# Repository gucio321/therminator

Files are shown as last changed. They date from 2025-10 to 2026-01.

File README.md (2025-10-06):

# Intro

This is a repository containing resources for my enviroumental physics project.

# Goals

The main goal of this project is to compare various types of thermal sensors in terms of their accuracy.

The expected result of the experiment is a decent set of data obtained automatically with a microcontroller setup.

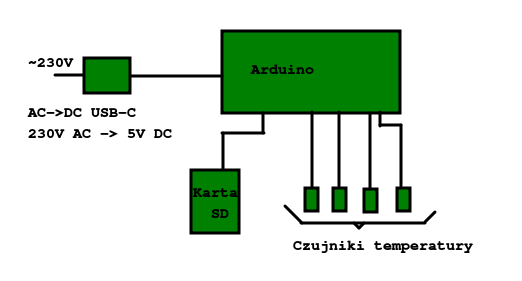
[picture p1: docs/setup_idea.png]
Setup overview


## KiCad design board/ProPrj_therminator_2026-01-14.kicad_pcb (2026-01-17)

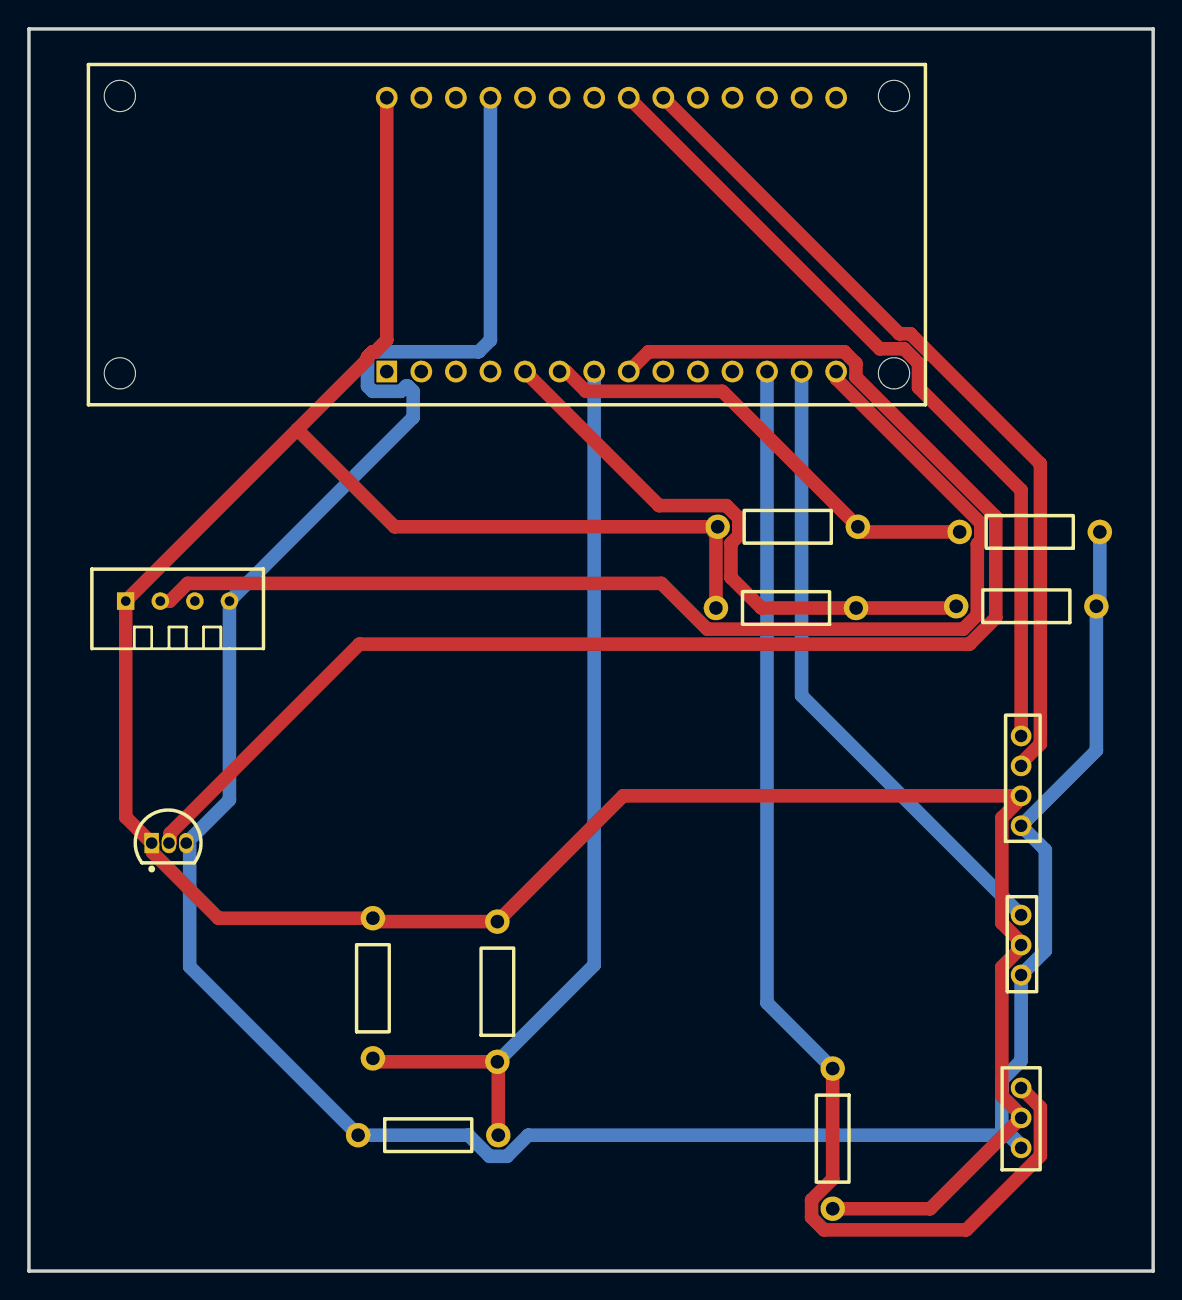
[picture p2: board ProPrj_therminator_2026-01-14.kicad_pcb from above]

Board: 2 copper layers, 82.6 x 91.3 mm, 14 parts (0 on the bottom side), 11 nets.

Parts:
DHT11: SENSOR-TH_DHT11-1
DHT22: DHT22-cable
DS18B20-1: DS18B20-cable
LCD-1: LCD-cable
LM35: TO-92-3_L4.8-W3.7-P1.27-L
NTC: RES-TH_BD2.3-L6.3-P10.30-D0.6
PT100-1, PT100-2: RES-TH_BD2.3-L6.3-P10.30-D0.6
R4: RES-TH_BD2.3-L6.3-P10.30-D0.6
RPom1, RPom2, RPom3, RPom4: RES-TH_BD2.3-L6.3-P10.30-D0.6
U1: COMM-TH_28P-L61.5-W25.0-P2.54

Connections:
$1N461: DHT11.1, DHT22.2, DS18B20-1.2, LCD-1.2, LM35.1, R4.2, RPom1.2, RPom2.2, RPom3.2, RPom4.2, U1.28
$1N571: DHT11.2, U1.14
$1N609: LM35.2, U1.8
$1N615: DHT11.4, DHT22.1, DS18B20-1.1, LCD-1.1, LM35.3, NTC.1, PT100-1.1, PT100-2.1, U1.25
$1N842: NTC.2, RPom1.1, RPom2.1, U1.7
$1N1258: DHT22.3, U1.13
$1N1408: DS18B20-1.3, R4.1, U1.12
$1N1586: PT100-1.2, RPom3.1, U1.6
$1N1590: PT100-2.2, RPom4.1, U1.5
$1N1838: LCD-1.3, U1.20
$1N1847: LCD-1.4, U1.21

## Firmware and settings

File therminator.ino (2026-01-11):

#include <DHT.h>
#include <OneWire.h>
#include <DallasTemperature.h>
#include <LiquidCrystal_I2C.h>
#include <SD.h>
#include <SPI.h>

const auto FILENAME = "datafile.csv";
const auto DHT11_PIN = 5;
const auto DHT22_PIN = 4;
const auto LM35_PIN = A6;
const auto DS18B20_PIN = 3;
const auto NTC_PIN = A5;
const auto NTC_R = 180000/2;
const auto VREF = 1.0;
auto const SUPPLY_V = 5.04;
auto const PT100_PIN = A4;
double const PT100_R = 673;
double const PT100_WIRES_R = 1.2;

DHT dht11(DHT11_PIN, DHT11);
DHT dht22(DHT22_PIN, DHT22);
OneWire oneWire(DS18B20_PIN);
DallasTemperature ds18b20(&oneWire);
LiquidCrystal_I2C lcd(0x27,  16, 2);

const int N_SENSORS = 7;
double record[N_SENSORS] = {0};
unsigned long MEASURE_IDX = 0;
char** names = new char*[N_SENSORS] {
  (char*)"DHT11 [oC]",
  (char*)"DHT22 [oC]",
  (char*)"LM35 [oC]",
  (char*)"DS18B20 [oC]",
  (char*)"NTC [R]",
  (char*)"PT100 [R]",
  (char*)"PT100 [oC]"
};

enum SensorType {
  DHT11_SENSOR,
  DHT22_SENSOR,
  LM35_SENSOR,
  DS18B20_SENSOR,
  NTC_SENSOR_R,
  PT100_SENSOR_R,
  PT100_SENSOR
};

int currentPage = 0;

void setup() {
  Serial.begin(9600);
  dht11.begin();
  dht22.begin();
  ds18b20.begin();
  analogReference(AR_INTERNAL1V0);

  lcd.init();
  lcd.backlight();
  lcd.setCursor(0,0);
  lcd.print("Hello from the");
  lcd.setCursor(0,1);
  lcd.print("Therminator!");
  
  // init SD card
  if (!SD.begin(SDCARD_SS_PIN)) {
    Serial.println("Cannott initialize SD card!");
    lcd.clear();
    lcd.setCursor(0,0);
    lcd.print("SD init failed!");
    bool backlight = true;
    while (1) {
      if (backlight) {
        lcd.backlight();
        backlight = false;
      } else {
        lcd.noBacklight();
        backlight = true;
      }
      delay(1000);
    }
  }

  Serial.println("SD init OK");
  lcd.clear();
  lcd.print("SD init OK.");
  lcd.setCursor(0,1);
  lcd.print("Saving header...");
  // save header
  String headerString = "#Idx,time,";
  for (int i = 0; i < N_SENSORS; i++) {
    headerString += String(names[i]);
    if (i < N_SENSORS - 1) {
      headerString += ",";
    }
  }
  File dataFile = SD.open(FILENAME, FILE_WRITE);
  if (dataFile) {
    dataFile.println(headerString);
    dataFile.close();
    Serial.println("Header saved: " + headerString);
  } else {
    Serial.println("Error opening file to save header!");
    lcd.clear();
    lcd.setCursor(0,0);
    lcd.print("SD write error!");
    bool backlight = true;
    while (1) {
      if (backlight) {
        lcd.backlight();
        backlight = false;
      } else {
        lcd.noBacklight();
        backlight = true;
      }
      delay(500);
    }
  }

}

void loop() {
  Serial.println("===========BEGIN============");
  MEASURE_IDX++;
  dht11Read();
  dht22Read();
  lm35Read();
  ds18b20Read();
  ntcRead();
  pt100Read();
  Serial.println("============END=============");
  // print the record on the screen

  currentPage++;
  if (currentPage >= N_SENSORS) {
    currentPage = 0;
  }

  // prepar data for save
  String dataString = String(MEASURE_IDX) + "," + String(millis()) + ",";
  for (int i = 0; i < N_SENSORS; i++) {
    dataString += String(record[i]);
    if (i < N_SENSORS - 1) {
      dataString += ",";
    }
  }

  lcd.print("SAVE!!");
  File dataFile = SD.open(FILENAME, FILE_WRITE);
  if (dataFile) {
    dataFile.println(dataString);
    dataFile.close();
    Serial.println("Data saved: " + dataString);
  } else {
    Serial.println("Error opening file!");
    lcd.clear();
    lcd.setCursor(0,0);
    lcd.print("SD write error!");
    bool backlight = true;
    while (1) {
      if (backlight) {
        lcd.backlight();
        backlight = false;
      } else {
        lcd.noBacklight();
        backlight = true;
      }
      delay(500);
    }
  }
  lcd.print("OK");

  lcd.clear();
  lcd.setCursor(0,0);
  lcd.print(names[currentPage]);
  lcd.setCursor(0,1);
  lcd.print("T=");
  lcd.print(record[currentPage]);
  lcd.print("  ");
  lcd.print(MEASURE_IDX);

  delay(1000);
}

void dht11Read() {
  Serial.print("DHT11: T = ");
  double temp = dht11.readTemperature();
  record[DHT11_SENSOR] = temp;
  Serial.print(temp);
  Serial.print(" *C\n");
}

void dht22Read() {
  Serial.print("DHT22: T = ");
  record[DHT22_SENSOR] = dht22.readTemperature();
  Serial.print(record[1]);
  Serial.print(" *C\n");
}

void lm35Read() {
  Serial.print("LM35: T = ");
  auto rawVal = analogRead(LM35_PIN);
  auto voltage = (VREF / 1023.0) * rawVal; // Convert ADC value to voltage
  auto temp = voltage * 100.0; // LM35 outputs 10mV per degree Celsius
  record[LM35_SENSOR] = temp;
  Serial.print(temp);
  Serial.print(" *C\n");
}

void ds18b20Read() {
  ds18b20.requestTemperatures();
  delay(1500);
  Serial.print("DS18B20: T = ");
  record[DS18B20_SENSOR]= ds18b20.getTempCByIndex(0);
  Serial.print(record[DS18B20_SENSOR]);
  Serial.print(" *C\n");
  Serial.println(ds18b20.getDeviceCount());
}

void ntcRead() {
  double rawVal = analogRead(NTC_PIN);
  Serial.print("NTC: ADC = ");
  Serial.print(rawVal);
  Serial.print("\n");

  double ntcV = rawVal / 1023.0 * VREF;
  Serial.print("NTC: V = ");
  Serial.print(ntcV);
  Serial.print(" V\n");

  double ntcR = ntcV*NTC_R/((SUPPLY_V - ntcV));
  Serial.print("NTC: R = ");
  Serial.print(ntcR);
  Serial.print(" Ohm\n");
  record[NTC_SENSOR_R] = ntcR;

  double B = 3380000;
  double ntcT = B/(log(ntcR/NTC_R) + B/298.15) - 273.15;
  Serial.print("NTC: T = ");
  Serial.print(ntcT);
  Serial.print(" *C\n");
}

void pt100Read() {
  double rawVal = analogRead(PT100_PIN);
  Serial.print("PT100: ADC = ");
  Serial.print(rawVal);
  Serial.print("\n");

  double pt100V = rawVal / 1023.0 * VREF;
  Serial.print("PT100: V = ");
  Serial.print(pt100V);
  Serial.print(" V\n");

  double pt100R = pt100V*PT100_R/((SUPPLY_V - pt100V)) - PT100_WIRES_R;
  Serial.print("PT100: R = ");
  Serial.print(pt100R);
  Serial.print(" Ohm\n");
  record[PT100_SENSOR_R] = pt100R;

  const double R0 = 100;
  const double A = 3.9827e-3;
  const double B = -5.775e-7;
  double pt100T = (-A + sqrt(A*A - 4*B*(1 - pt100R/R0)))/(2*B);
  Serial.print("PT100: T = ");
  record[PT100_SENSOR] = pt100T;
  Serial.print(pt100T);
  Serial.print(" *C\n");
}

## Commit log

2025-12-19 therminator implement some sensors
2026-01-08 pt100: adjust values and cosider wires resistance
2026-01-17 add board info
    [ProPrj_therminator_2026-01-14.kicad_pcb, ProPrj_therminator_2026-01-14.kicad_sch]
